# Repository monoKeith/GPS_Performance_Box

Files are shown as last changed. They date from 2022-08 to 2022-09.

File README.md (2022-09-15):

# GPS_Performance_Box
Performance box based on ublox-GPS-module and ESP32 S2

## Video

[0 - 100 KPH test](https://youtu.be/5jb0r1BLMyU)

## Pics

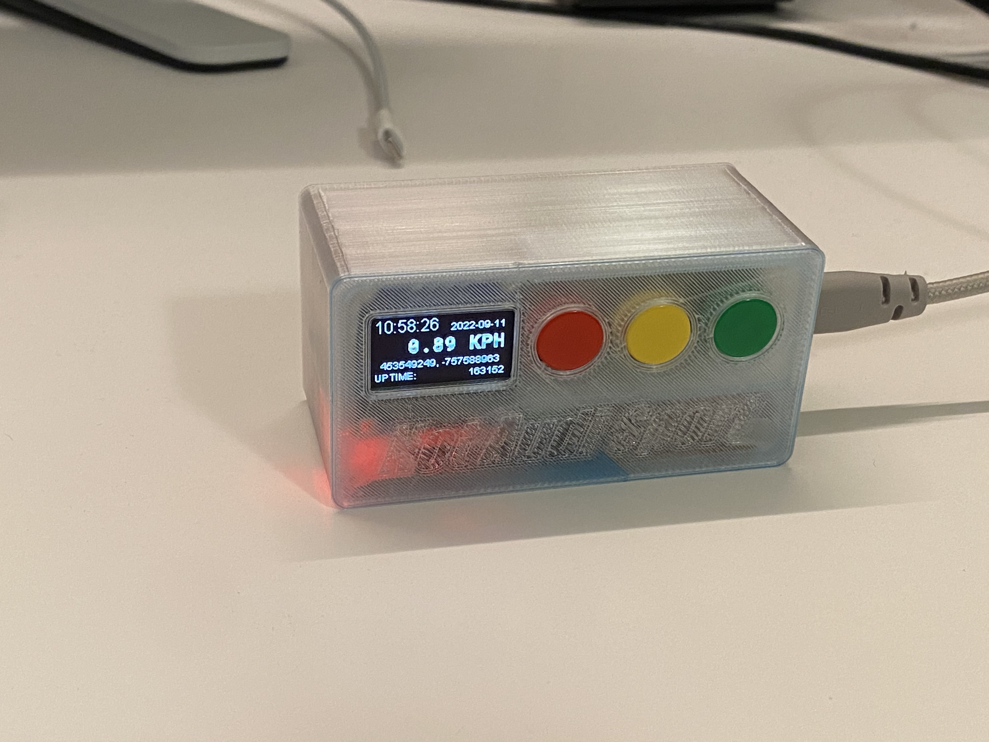
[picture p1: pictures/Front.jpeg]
Front


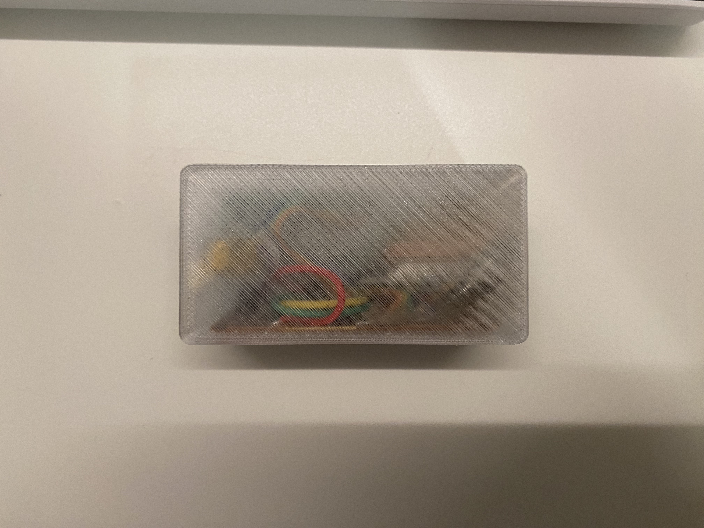
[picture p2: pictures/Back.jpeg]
Back


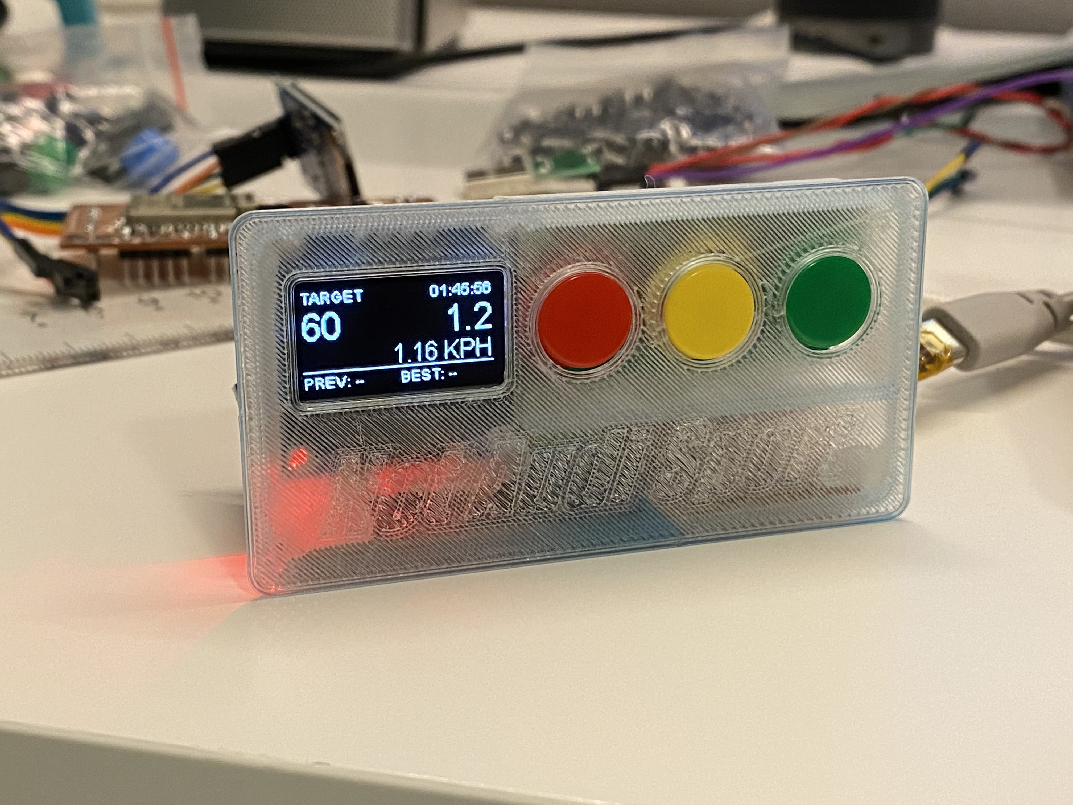
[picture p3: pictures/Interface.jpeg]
Interface


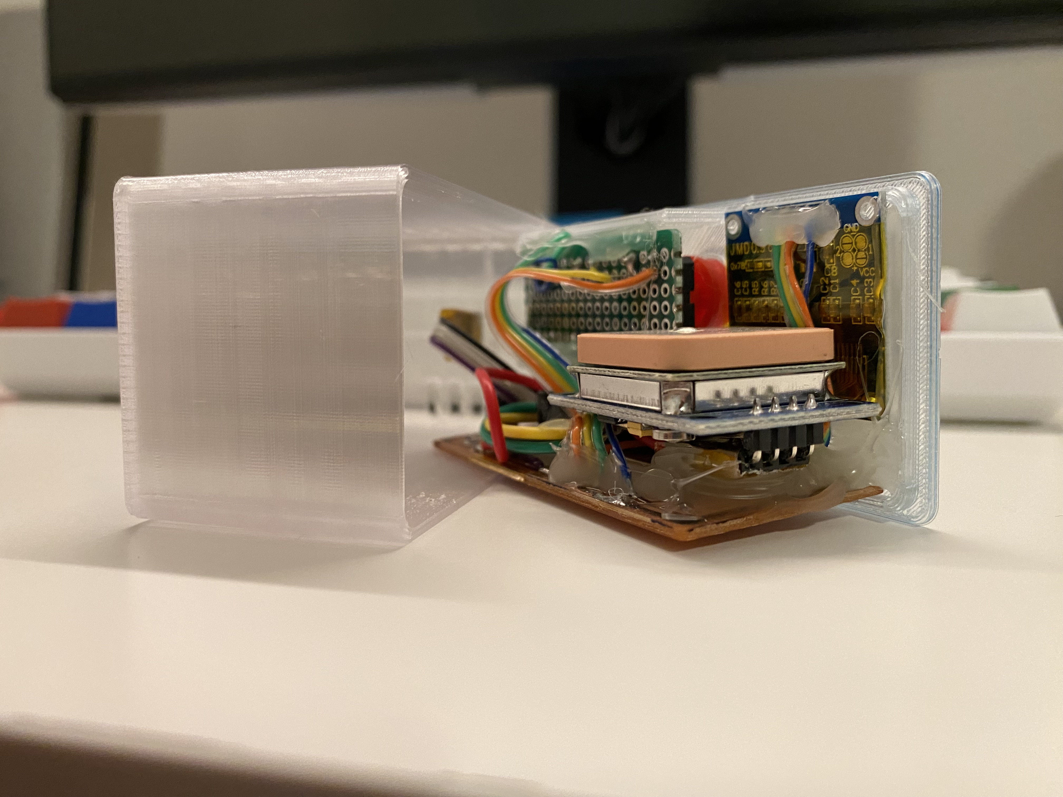
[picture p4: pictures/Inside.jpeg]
Inside


---
## Purpose

The purose of this project is to implement a GPS location based speedometer to test acceleration of my car. 

Similar products like [dragy](https://dragymotorsports.com) does not have a display so requires an APP and connection to a phone to work, although it provides more detail it's not very convenient to use.

This project is based on ESP32, so WiFi and Bluetooth connectivity is already onboard just require more software to make it work. And there're redundant IO ports to connect more sensors like an accelerometer, to improve or compensate the results from GPS.

## Functionality

There's 4 different screen.

- Debug screen: shows time, date, speed, location, system uptime
- 0 - 60 timer
- 0 - 80 timer
- 0 - 100 timer

Use yellow button to go to previous screen, use green button to go to next screen. In a timer screen, press red button can reset the results of the displaying timer.

Each of these 3 timers runs in background simultaneously, no need to be in a specific screen.

Automatically test acceleration, all timers are automatically triggered when speed change from 0 - 1, and will automatically stop when the target speed is reached. If target is not reached and speed falls back to 0, the timer resets and wait for speed to change from 0 - 1.

## Issues

- Currently I've noticed that the GPS speed is not reliable at low speed. It constantly jumps between 0 - 1 KPH when it's not moving at all. So instead of testing acceleration of like 0 - 100, it's actually testing 1 - 100. A future update to use accelerometer as timer trigger may mitigate this issue.

- The breakout board design was from my other project, so it wasn't optimized for the space and hardware of this project. All IO connections coulbe be routed in a better way to achieve a much compact design.

- It doesn't have a battery, requires USB power to work.

## Libraries
[SparkFun u-blox GNSS Arduino Library](https://github.com/sparkfun/SparkFun_u-blox_GNSS_Arduino_Library)

[Thingpulse ESP32 OLED driver for SSD1306](https://github.com/ThingPulse/esp8266-oled-ssd1306)

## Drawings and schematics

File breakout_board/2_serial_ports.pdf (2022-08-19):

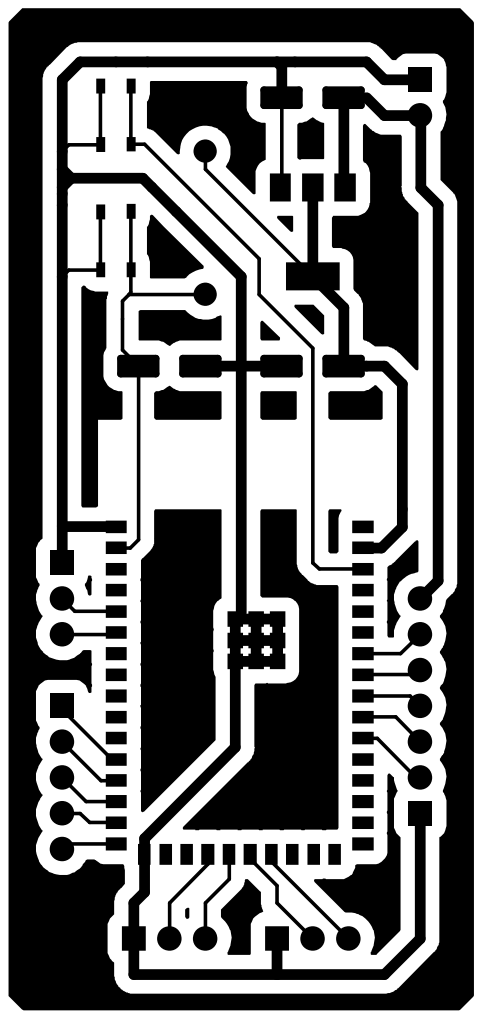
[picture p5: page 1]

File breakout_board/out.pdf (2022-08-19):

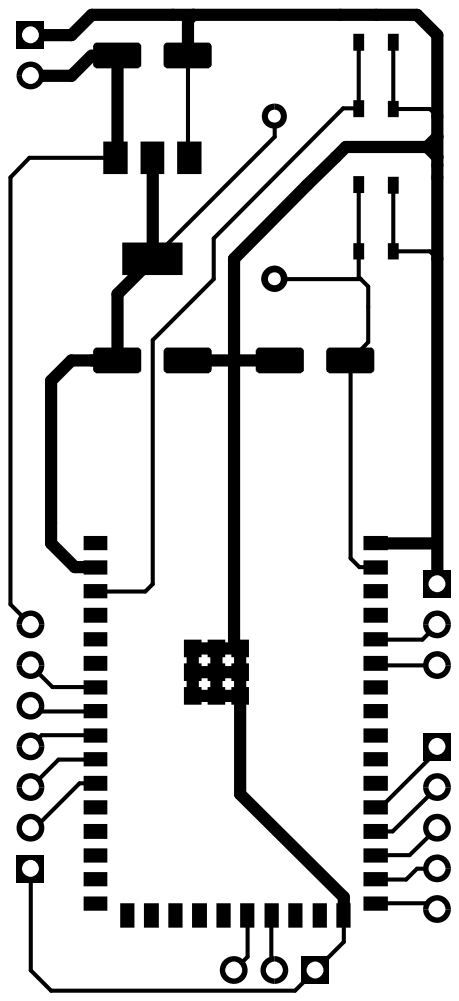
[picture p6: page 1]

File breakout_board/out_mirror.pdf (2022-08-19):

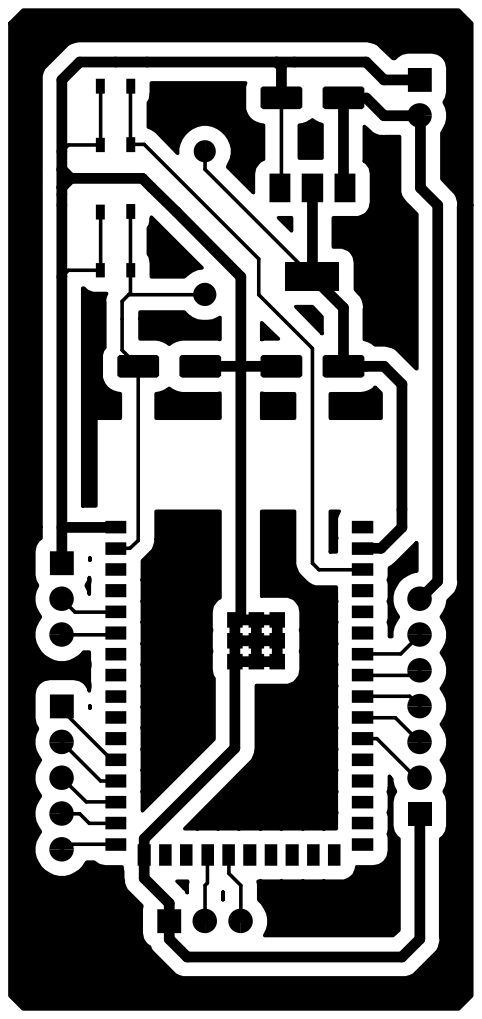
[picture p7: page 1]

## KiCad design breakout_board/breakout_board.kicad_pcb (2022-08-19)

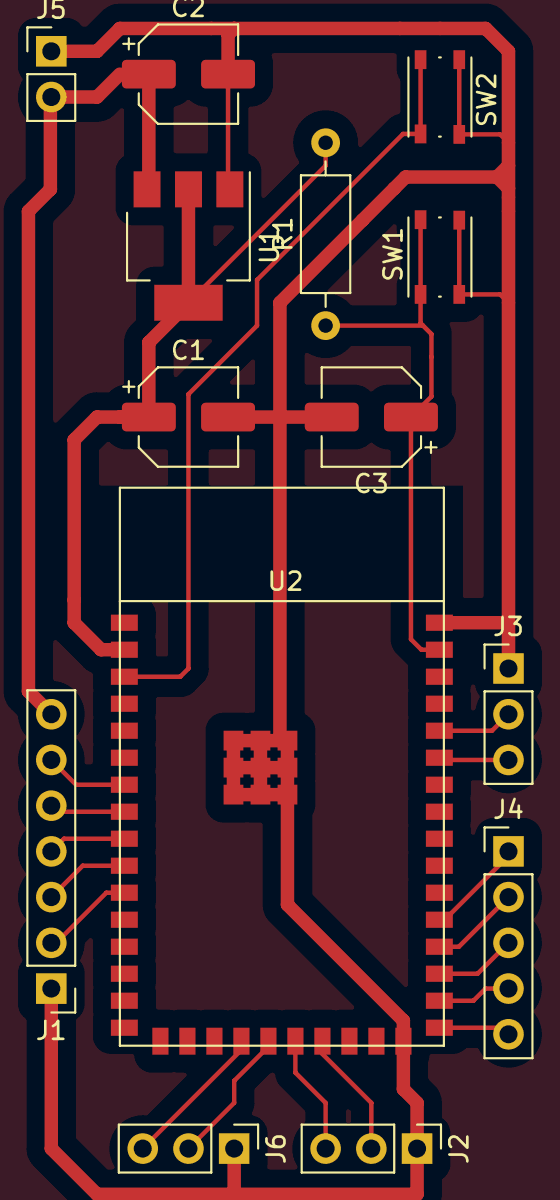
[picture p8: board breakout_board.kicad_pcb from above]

Board: 2 copper layers, 14 parts (0 on the bottom side), 21 nets.

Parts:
C1: 10uF; CP_Elec_5x5.9
C2: 20uF; CP_Elec_5x5.9
C3: 1uF; CP_Elec_5x5.9
J1: FrontPanel; PinHeader_1x07_P2.54mm_Vertical
J2: USB; PinHeader_1x03_P2.54mm_Vertical
J3: Serial 0; PinHeader_1x03_P2.54mm_Vertical
J4: OUT; PinHeader_1x05_P2.54mm_Vertical
J5: Conn_01x02; PinHeader_1x02_P2.54mm_Vertical
J6: Serial 1; PinHeader_1x03_P2.54mm_Vertical
R1: 10K; R_Axial_DIN0207_L6.3mm_D2.5mm_P10.16mm_Horizontal
SW1: Reset; SW_Push_1P1T_NO_Vertical_Wuerth_434133025816
SW2: Boot; SW_Push_1P1T_NO_Vertical_Wuerth_434133025816
U1: AMS1117-3.3; SOT-223-3_TabPin2
U2: ESP32-S2-WROOM

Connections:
+3V3: C1.1, R1.2, U1.2 (VO), U2.2 (3V3)
+5V: C2.1, J1.7, J5.2, U1.3 (VI)
GND: C1.2, C2.2, C3.2, J1.1, J2.1, J3.1, J5.1, J6.1, SW1.2, SW2.1, U1.1 (GND), U2.26 (GND), U2.42 (GND), U2.43 (EPAD)
unnamed: C3.1, R1.1, SW1.1, U2.41 (EN)
unnamed: J1.2, U2.11 (IO8)
unnamed: J1.3, U2.10 (IO7)
unnamed: J1.4, U2.9 (IO6)
unnamed: J1.5, U2.8 (IO5)
unnamed: J1.6, U2.7 (IO4)
unnamed: J2.2, U2.23 (IO20)
unnamed: J2.3, U2.22 (IO19)
unnamed: J3.2, U2.38 (RXD0)
unnamed: J3.3, U2.37 (TXD0)
unnamed: J4.1, U2.31 (IO37)
unnamed: J4.2, U2.30 (IO36)
unnamed: J4.3, U2.29 (IO35)
unnamed: J4.4, U2.28 (IO34)
unnamed: J4.5, U2.27 (IO33)
unnamed: SW2.2, U2.3 (IO0)
unnamed: J6.3, U2.20 (IO17)
unnamed: J6.2, U2.21 (IO18)

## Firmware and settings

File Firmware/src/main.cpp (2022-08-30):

#include <Arduino.h>
#include <monitor.h>
#include <gps.h>
#include <config.h>
#include "state.h"
#include "ioControl.h"

// Stack sizes
#define STACK_SIZE_SMALL 32768
#define STACK_SIZE_TINY 16384

void monitorThread(void *pvParameters)
{
    while (true)
    {
        // Refresh monitor, takes about 20ms?
        monitor::refresh();
        // Delay 50ms, ~14 fps
        delay(50);
    }
}

void gpsLocationThread(void *pvParameters)
{
    while (true)
    {
        gps::updateLocation();
        delay(20);
    }
}

void gpsTimeThread(void *pvParameters)
{
    while (true)
    {
        gps::updateTime();
        delay(200);
    }
}

void setup()
{
    // IO
    ioControl::setup();
    // Boot screen
    monitor::setup();
    monitor::drawBootScreen();
    // Timers
    state::initTimers();
    // Setup GPS
    gps::setup();
    // Start Threads
    xTaskCreate(gpsLocationThread, "GPS Location Thread", STACK_SIZE_SMALL, NULL, 10, NULL);
    xTaskCreate(gpsTimeThread, "GPS Time Thread", STACK_SIZE_SMALL, NULL, 5, NULL);
    xTaskCreate(monitorThread, "Monitor Thread", STACK_SIZE_SMALL, NULL, 2, NULL);
}

void loop()
{
    state::refresh();
    delay(50);
}

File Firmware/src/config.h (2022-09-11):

#ifndef CONFIG_H
#define CONFIG_H

/* GPIO Pins */

#define SDA_PIN 37
#define SCL_PIN 36

#define BTN_RED 4
#define BTN_YELLOW 5
#define BTN_GREEN 6

#define BAUD_DEBUG 115200

/* Display */

// Shift UI in regular screen, positive = down, negative = up
#define SCREEN_Y_OFFSET 7

// How long should a message (light on / off) stay on display?
#define MSG_DISPLAY_MS 3000

/* GPS Module */

#define BAUD_DEFAULT 9600
#define BAUD_TARGET 921600
#define GNSS_REFRESH_RATE 10

/* Timer */

#define ROLLING_THRESHOLD 1

/* Buttons */

#define DEBOUNCE_MS 150

#define MODE_BUTTON_PIN 0   // GPIO 0 (boot button)

#endif

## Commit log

2022-08-19 Add PCB design
    [breakout_board.kicad_pcb, breakout_board.kicad_sch, breakout_board.sch]
2022-08-23 Set GPS 10Hz report rate
2022-08-26 [WIP] Timer
2022-08-27 Timer bug fix
2022-08-30 Button: switch between display modes
2022-09-11 [WIP] 3 Buttons support
2022-09-11 Refactor Timer UI
